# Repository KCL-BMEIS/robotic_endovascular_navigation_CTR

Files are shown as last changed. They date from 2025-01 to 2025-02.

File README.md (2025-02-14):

## Robotic Navigation with Catheter and Guidewire
This Git repository provides the basic hard- and software pieces to setup and control the endovascular robot presented at the Hamlyn Symposium 2025 by Seyedmohammadhadi Sadati (m.hadi.sadati@gmail.com).

Please find a comprehensive video about this research project [here](https://www.youtube.com/watch?v=b7-3ZVEUGTk).

Overview of the endovascular robot for catheter-guidewire navigation

# Hardware
The hardware components provided include the bill of materials to replicate the robotic hardward as well as the required .stl files for 3D-printing.

# Software
The software component is found "robotic_control.py". It serves as a basic user interface, letting the user control the robot's translation and rotation with a standard USB keyboard.

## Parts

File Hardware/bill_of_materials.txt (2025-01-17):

#	Label										Info - Specs						Amount		Example-Link
-----------------------------------------------------------------------------------------------------------------------------------------------------------------------------
-----------------------------------------------------------------------------------------------------------------------------------------------------------------------------
1. 	FRAME
1.1		Aluminium extrusion						20x20 with V-slot					-			-
1.2 	+ connectors etc.						-									-			-
1.3		Lead screw								Tr 8x4								1x			-
1.4		Lead screw nuts							Tr 8x4, 4mm lead, 2mm pitch			2x			https://www.amazon.co.uk/sourcing-map-Trapezoidal-Replacing-Accessories/dp/B0DPC3KCS1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
1.5		3D printed tip antenna flange			tip_antenna_flange					4x			-
-----------------------------------------------------------------------------------------------------------------------------------------------------------------------------
2. 	CARRIAGE (one per instrument, providing 1 DOF translation + 1 DOF rotation)
2.1		Hollow shaft stepper motor				NEMA 17 12v 1A						1x			-
2.2 	Non-captive stepper motor				NEMA 17 Tr 8x4						1x			https://www.aliexpress.com/item/1005003623545552.html?spm=a2g0o.order_list.order_list_main.4.79351802kYv4Zy
2.3 	Carrying pad							20mm V								1x			https://www.amazon.co.uk/dp/B09B396WH9/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
2.4 	Shaft Coupler Connector					10mm to 10mm, L25xD20				1x			https://www.amazon.co.uk/dp/B08H25TJ85/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					
2.5		Metal rod								D = 5mm								-			-
2.6 	Brass Drill Chuck						-									-			https://www.amazon.co.uk/dp/B08SC2QM2X/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							
2.7 	Telescopic antenna						-									1x			https://www.amazon.co.uk/dp/B0CLCSTB5M/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
2.8 	3D printed antenna flange				motor_anthena_flange.stl			2x			-
2.9		3D printed triangular motor mount		Motor Mount.stl						1x			-
2.10	3D printed rod carrier					Rod_carrier.stl						1x			-
2.11 	3D printed split rod carrier			Split_rod_carrier.stl				1x			-
2.12	3D printed split counter slider			Robot_CounterSlider.stl				1x			-
-----------------------------------------------------------------------------------------------------------------------------------------------------------------------------
3.	Electronics
3.1 	Control board							BIGTREETECH Octopus V1.1			1x			https://www.amazon.co.uk/dp/B094NG4D17/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
3.2 	Motor driver							BIGTREETECH TMCj2209 V1.3			2x			https://www.amazon.co.uk/dp/B07WC71M4R/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	
3.3 	Cable sleeve							-									1x			https://www.amazon.co.uk/dp/B07FW86XV6/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
3.4		Cables (stepper motor)					XH2.54								2x			https://www.amazon.co.uk/dp/B091FJ22TT/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						
-----------------------------------------------------------------------------------------------------------------------------------------------------------------------------
4.	End-switch setup 
4.1		Mechanical end switch 					-									2x			https://www.amazon.co.uk/dp/B07VWRS24K/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	
4.2		Metal rods for motor block switch		D = 5mm								1x			-
4.3		3D printed end stop connectors			Endstop_connecter.stl				1x			-		
4.4		3D printed shield connectors			motor_mech_shield_stopper.stl		1x			-

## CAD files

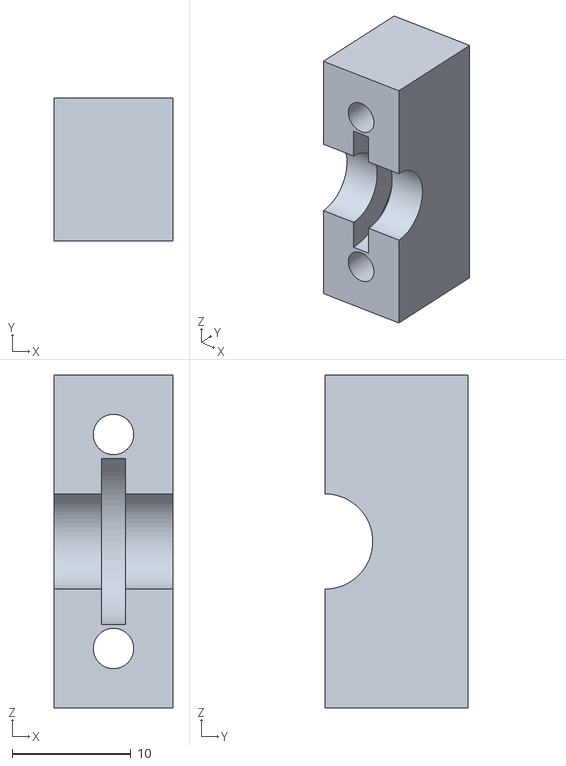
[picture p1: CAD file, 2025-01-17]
Hardware/CAD/Robot_CounterSlider.stl
10.0 x 12.0 x 28.0

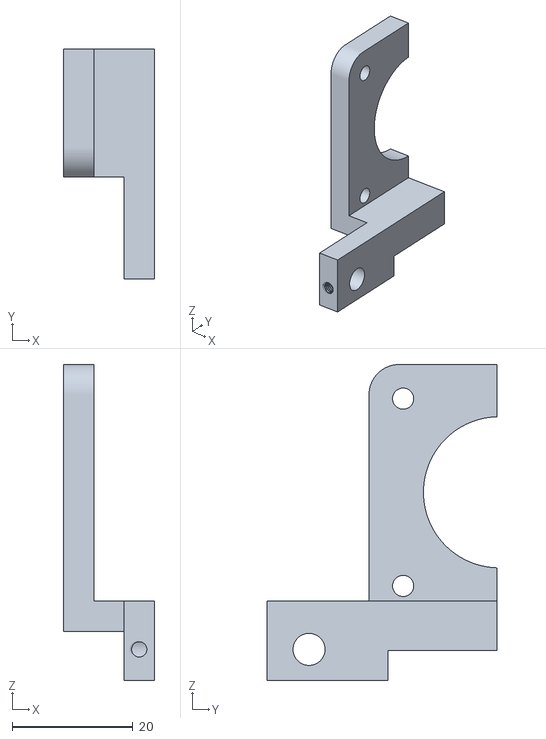
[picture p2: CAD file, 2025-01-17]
Hardware/CAD/motor_mech_shield_stopper.stl
15.0 x 38.0 x 52.3

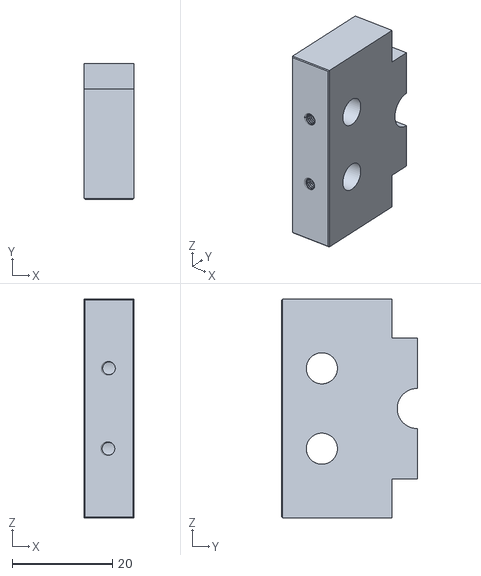
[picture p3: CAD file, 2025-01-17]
Hardware/CAD/Split_rod_carrier.stl
10.0 x 27.0 x 43.6

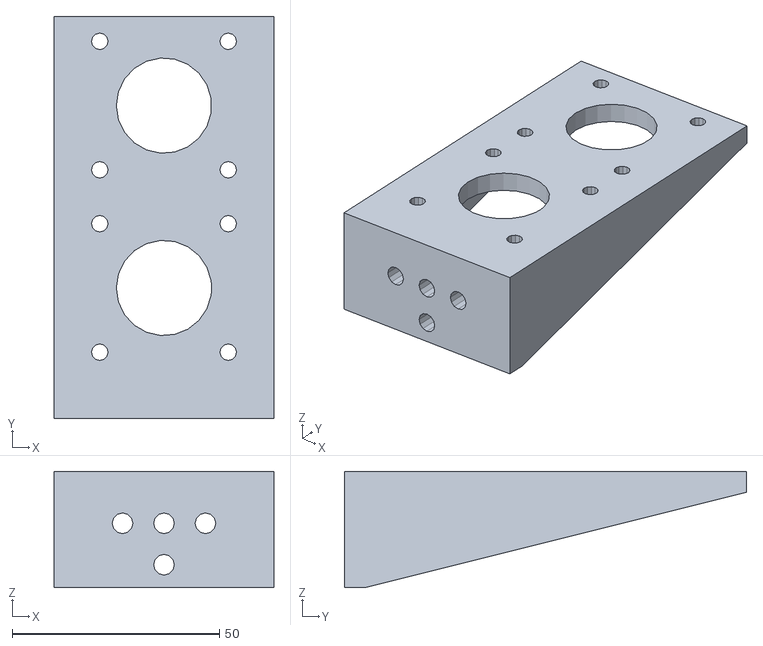
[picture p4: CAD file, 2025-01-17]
Hardware/CAD/Motor Mount.STL
53.0 x 97.0 x 28.0

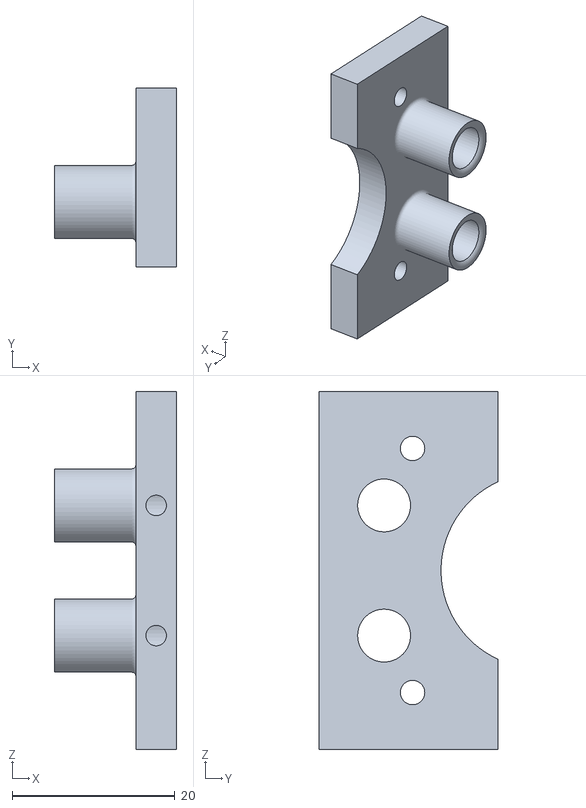
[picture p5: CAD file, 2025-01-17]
Hardware/CAD/Rod_carrier.stl
15.0 x 22.0 x 44.0

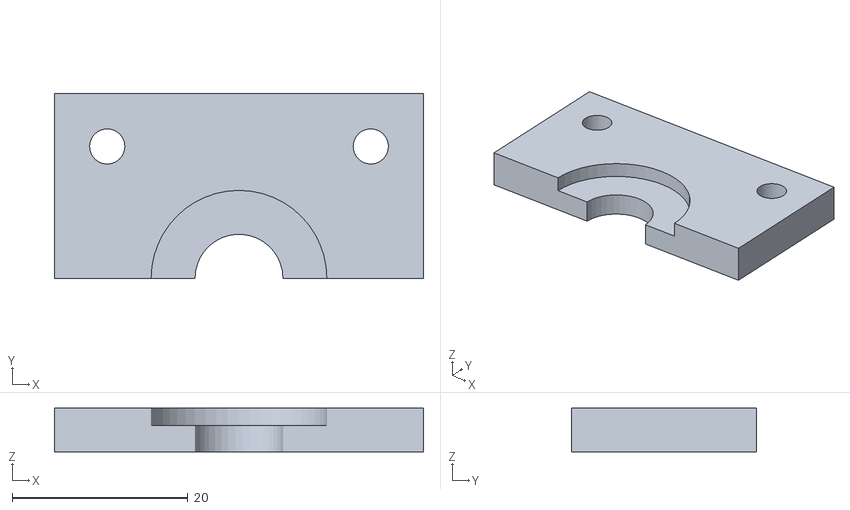
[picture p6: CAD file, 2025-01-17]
Hardware/CAD/motor_antenna_flange.STL
42.0 x 21.0 x 5.00

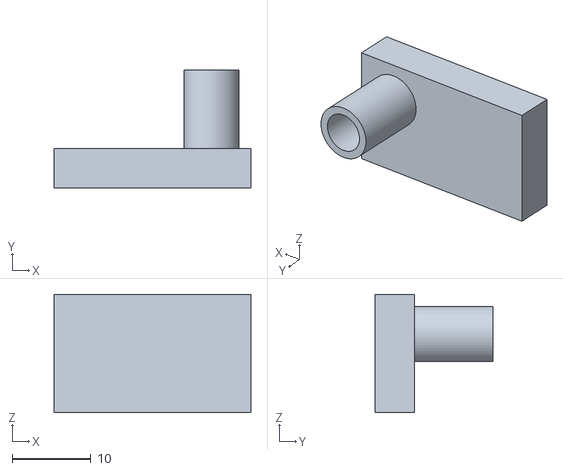
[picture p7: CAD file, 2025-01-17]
Hardware/CAD/Endstop_connecter.stl
25.0 x 15.0 x 15.0

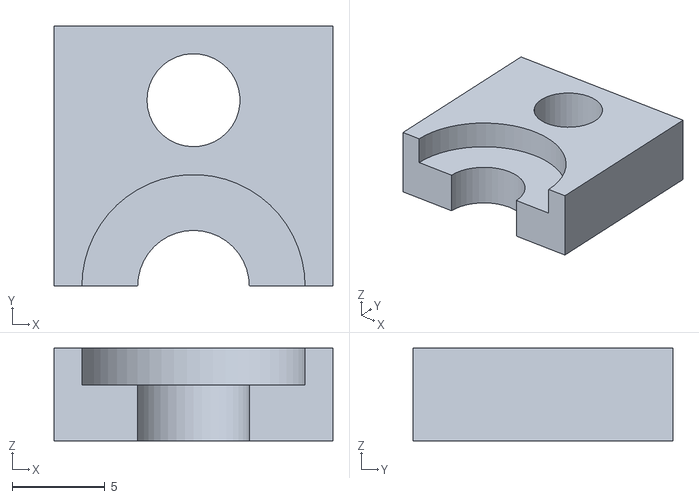
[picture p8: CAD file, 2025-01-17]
Hardware/CAD/tip_antenna_flange.STL
15.0 x 14.0 x 5.00

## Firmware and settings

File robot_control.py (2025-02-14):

from urllib import response
import numpy as np 
import matplotlib.pyplot as plt
import serial
from datetime import datetime
# import matlab.engine
import re

from time import perf_counter, sleep
import os
import math

# import keyboard
# from inputs import get_key
import msvcrt


# colors
WHITE = '\033[37m'
GREEN = '\033[32m'
YELLOW = '\033[33m'
BLUE = '\033[34m'
RED = '\033[31m'
CYAN = '\033[36m'
PURPLE = '\033[35m'
ENDC = '\033[0m'
BOLD = '\033[1m'
UNDERLINE = '\033[4m'

## parameters
# catheter parameters
CATH_NUMBERS = 1 # the number of catheters present in the video
l0_cath = [0, 0, 0] # inserted cath points

# controller parameters
image_frequency = 7.5 # controller frequency
# control2cnc = [[2, 5], [1, 4], [0, 3]] # [[translation1, rotation1]_innermost, ..., [translationN, rotationN]_outermost], trans and rot correspond to cnc board actuator number [XYZ_outer2inner rot_outer2inner]
control2cnc = [[1, 4], [0, 3], [2, 5]] # Lennart's single device tests
target_converg_range = 0.1 # target convergance radius to stop the controller

# cnc controller parameters:
CNC_CONNECT = True # should connect to the board or not
board_com = [ 'COM3' ] # port addresses for layer (top) 1 - 4 (bottom), my laptop
motor_code = [ 'X' , 'Y' , 'Z' , 'A' , 'B' , 'C' ] # motor gcodes, XYZ_outer2inner: translation, ABC_outer2inner: rotation, XA: for outermost
feedrate = 15000 # axis feedrate in mm/min (the commands are in mm)
dist_scale = [10, 10, 10, 1/9, 1/9, 1/9] # motor step scale factor to get mm and deg units
travel_step = 5 # mm, travel distance stepkk
rot_step = 30 # deg, rotation angle step


## functions
# keyboard input
def keyboard_input():
    if msvcrt.kbhit():
        keyboard_input = ord( msvcrt.getch() )
        while(msvcrt.kbhit() ): # empty the keyboard buffer due to rapid key press
            keyboard_input = ord( msvcrt.getch() )
    else:
        keyboard_input = -1
    # print(keyboard_input) # test
    return keyboard_input
 
# send/receive gcode commands
def command(board_serials, board_no, command):
    global CNC_CONNECT        
    response = '' # default pos response
    
    if CNC_CONNECT:
        # print( YELLOW + 'board ' + str( board_no) + ' - ' + command )        
        board_serials[board_no].write(str.encode(command + '\r\n')) 
        # sleep(0.1)

        while True:
            line = board_serials[board_no].readline()
            if line == b'ok\n':
                break
            # print( BLUE + 'Board response: ' )
            # print( line )
            response = line

    return response

# get current position
def get_pos(board_serials):
    global CNC_CONNECT
    pos = [ [ 0.0, 0.0, 0.0, 0.0, 0.0, 0.0 ] ] # position vector for all motors on 1st cnc board
    if CNC_CONNECT:
        for i_board in range(0,1):
            response = command(board_serials, i_board, 'M114 R')
            # command(board_serials, i_board, 'M400') # wait until the motion is finished
            pos_list = re.findall(r"[-+]?(?:\d*\.\d+|\d+)", response.decode('utf-8')) # find float numnbers in the line
            # print(pos_list)
            for i in range(0,6):
                pos[i_board][i] = float( pos_list[i] ) / dist_scale[i] # scale to mm and deg
    # print(pos) # test
    return pos

# pass line length values
def dist2gcode( board_serials , dist ):
    global feedrate
    command_str = [ 'G1' ]
    for i in range(0,6) : # itterate tendon#
        # command_str[ 0 ] += ' ' + motor_code[ i ] + str( int( dist[i]*dist_scale[i] ) ) # scale to mm and deg
        command_str[ 0 ] += ' ' + motor_code[ i ] + str( ( dist[i]*dist_scale[i] ) ) # scale to mm and deg
        
    for i in range(0,1) : # call the cnc drivers
        command_str[i] += ( ' F' + str(feedrate) ) # add velocity info
        print( BLUE + board_com[i] + ': ' + command_str[i] )
        command( board_serials, i , "G91" ) # set to relative positioning
        command( board_serials, i , command_str[i] )
    
# check if the motion is finished
def motion_completed(board_serials,abs_encoder):
    pos = get_pos(board_serials) # get current pos
    # print(WHITE + str(pos)) # test
    # print(WHITE + str(abs_encoder)) # test
    
    for i in range(0,6):
        if abs( pos[0][i] - abs_encoder[i] ) < 0.1 :
            MOTOIN_STATE = True # remain True only if all axes are reached
        else:
            MOTOIN_STATE = False # returns false and terminate the code with first not reached axis
            break    
    return MOTOIN_STATE

# stop the controller if the target is reached
def target_reached(target_coords,tracking):
    TARGET_REACHED = False
    error = np.sqrt( np.power(target_coords[0][0]-tracking[0][0],2) + np.power(target_coords[0][1]-tracking[0][1],2) )
    if error < target_converg_range:
        TARGET_REACHED = True
    return TARGET_REACHED

## initialize cnc board
board_serials = [0]
if CNC_CONNECT:
    for i in range( 0 , 1 ) : # start the boards
        print(WHITE + 'Starting board on port ' + board_com[i] + '...')
        board_serials[i] = serial.Serial(board_com[i], 250000)
        sleep(2)
        command(board_serials, i, "G92 X0 Y0 Z0 A0 B0 C0") # set current (home) position


# ## initialize matlab
# eng = matlab.engine.start_matlab()
# eng.addpath(r'C:\Hadi\Postdoc\2_KCL\5. Spinoff\1. STREAM - SCS + Kaspar\3. Model\0. CC',nargout=0)


## program main loop
dist = [0, 0, 0, 0, 0, 0] # travel distance/rotation reset
abs_encoder = [0, 0, 0, 0, 0, 0]

UPDATED_INPUT = 0 # is input updated? 1 to calculate the default pose
t_prev_cmd = 0 # time previous command sent
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

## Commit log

2025-01-17 readme update, CAD upload
    [Endstop_connecter.stl, Motor Mount.STL, Rod_carrier.stl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]
2025-01-17 updated bill of materials
    [Robot_CounterSlider.stl, Split_rod_carrier.stl, motor_mech_shield_stopper.stl]
2025-01-17 finalized bill of materials
2025-01-31 updated files
    [branch0-new.csv, branch0.csv, branch1-new.csv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]
